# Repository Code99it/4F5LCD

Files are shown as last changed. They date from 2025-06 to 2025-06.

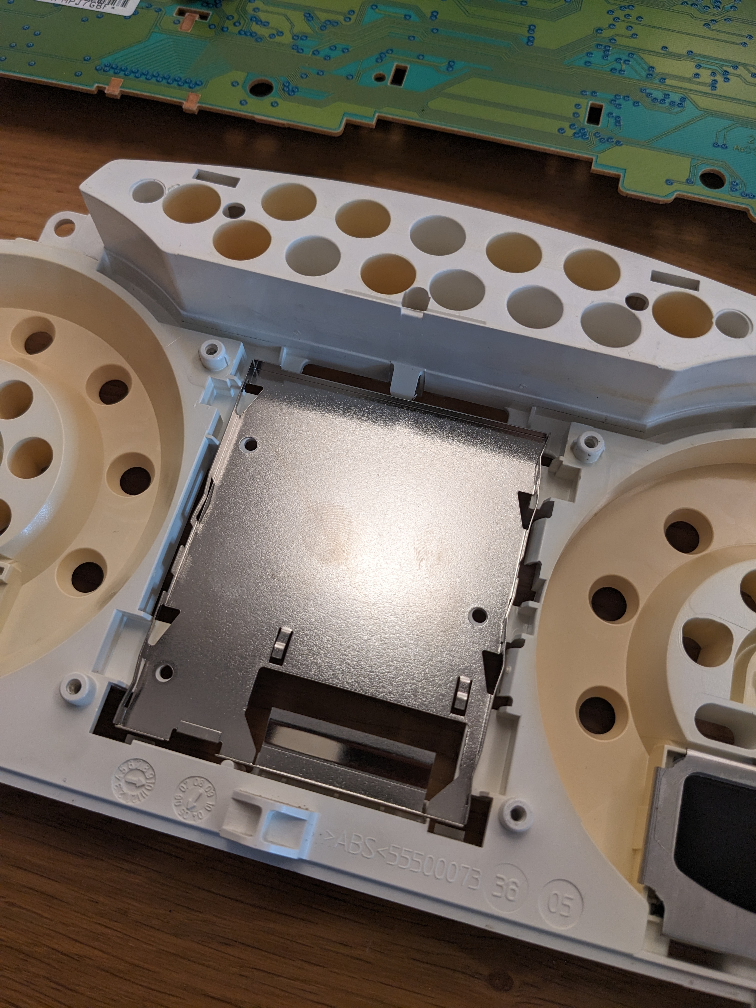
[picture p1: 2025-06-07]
Solution 2 - Disassembling the speedometer and fitting a 3.5 inch display/PXL_20250607_092634435.jpg

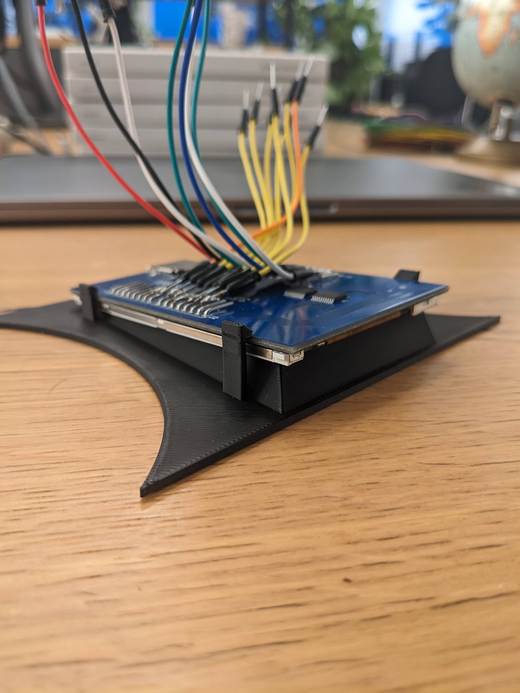
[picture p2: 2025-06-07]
Solution 1 - 3D printed mounting frame for the LCD/PXL_20250601_192043505.jpg

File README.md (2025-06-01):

# Installation und Nutzung  
# Installation and Usage  

**Dieses Projekt ersetzt bei Fahrzeugen der VAG-Gruppe mit Plattform 4F (C6) das kleine Display in der Mitte des Kombiinstruments durch eine spezielle Mikrocontroller-Lösung. Die Bedienung erfolgt über die linken Tasten am Lenkrad:**  
- Drehen am Rad wählt einen Listeneintrag.  
- Klicken auf das Drehrad aktiviert den gewählten Eintrag.  
- Die MODE-Taste am Lenkrad wechselt zwischen den Menüseiten.  
- Die Auf-Ab-Taste am Wischerhebel und die Bestätigungstaste auf der Hebel-Unterseite sind zunächst wirkungslos, die Funktion wird ggf. in späteren Projektversionen noch einmal aufgegriffen.

**This project replaces the small display in the center of the instrument cluster with a custom microcontroller solution for vehicles of the VAG group using platform 4F (C6). Operation is via the left steering wheel controls:**  
- Rotating the knob selects a list item.  
- Pressing the knob activates the selected item.  
- The MODE button on the steering wheel switches between menu pages.  
- The up/down button on the wiper stalk and the confirm button on the underside of the stalk are initially non-functional; this feature may be revisited in a future project version.

## Was dir dieses Projekt nützt  
## What This Project Does for You  

- Du erhältst schnellen, sicheren Zugriff auf fahrzeuginterne Statusdaten, um Temperatur-, Drehzahl- oder Komfortparameter zu überwachen.  
- You get fast, secure access to in-vehicle status data to monitor temperature, RPM, or comfort parameters.  

## 1. Systemzugriff einrichten  
## 1. Set Up System Access  

- Dieses System greift ausschließlich lesend auf die fahrzeuginternen Bussysteme (z. B. CAN-Bus) zu.  
- Es werden nur Statusinformationen wie Temperatur, Drehzahl oder Komfortdaten erfasst.  
- Kein Zugriff auf sicherheitskritische Systeme (Bremsen, Airbags, ESP, ABS, Antrieb).  
- Eine Beeinflussung, Veränderung oder Steuerung dieser Systeme ist weder vorgesehen noch implementiert.  

- No access to safety-critical systems (brakes, airbags, ESP, ABS, drivetrain).  
- Only status information such as temperature, RPM or comfort data is collected.  
- This system uses read-only access to the vehicle’s internal bus systems (e.g. CAN bus).  
- Any manipulation, alteration or control of these systems is neither intended nor implemented.  

## 2. Infotainment-Funktionen aktivieren  
## 2. Enable Infotainment Functions  

- Für Menüauswahl und Displayanzeige wird schreibender Zugriff auf nicht sicherheitsrelevante Steuergeräte verwendet.  
- Dieser Zugriff ist funktional begrenzt und beeinflusst weder Fahrverhalten noch Fahrsicherheit.  

- Write access to non-safety-critical control units is used for menu selection and display output.  
- This access is functionally limited and does not affect driving behavior or safety.  

## 3. CAN-Bus-Analyse durchführen  
## 3. Perform CAN-Bus Analysis  

- Sniffing im Rahmen des gesetzlich zulässigen Reverse Engineering (§ 69e UrhG) zur Interoperabilität.  
- Es wird keine Original-Software extrahiert, kopiert oder verändert – nur das Datenverhalten dokumentiert.  

- Sniffing under the legally permitted reverse engineering (§ 69e UrhG) for interoperability.  
- No original software is extracted, copied, or modified – only data behavior is documented.  

## 4. Nutzungshinweise  
## 4. Usage Notes  

- Du nutzt das System ausschließlich zu Test-, Entwicklungs- oder Forschungszwecken.  
- Dauerbetrieb im öffentlichen Straßenverkehr erfordert Einzelabnahme (§ 21 StVZO) bei TÜV/DEKRA etc.  

- Use exclusively for testing, development, or research purposes.  
- Permanent use on public roads requires single-vehicle approval (§ 21 StVZO) from TÜV/DEKRA, etc.  

## 5. Haftungsausschluss  
## 5. Disclaimer  

- Nicht autorisiert, geprüft oder freigegeben durch einen Fahrzeughersteller; keine offizielle Verbindung zu Herstellern der VAG-Gruppe.  
- Jegliche Nutzung erfolgt auf eigene Verantwortung.  

- Not authorized, tested, or approved by any vehicle manufacturer; no official affiliation with any brand of the VAG group.  
- Any use is at your own risk.

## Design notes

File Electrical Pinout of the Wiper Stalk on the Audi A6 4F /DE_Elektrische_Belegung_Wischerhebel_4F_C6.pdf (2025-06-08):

## Elektrische Belegung des Wischerhebels Audi A6 4F

Leitungen im Hebel: | Steckeranschluss:
rot | 1 | rot
gelb | 2 | gelb
grün | 3 | grün
4 | kein PIN
5 | nicht belegt
6 | nicht belegt

Widerstandsnetzwerk für die Tasten:

rot
grün

Widerstandsnetzwerk für den Drehgeber:

rot
gelb
Tastendruck | Leitungen | Widerstand
Reset | rot-grün | 330 Ohm
Up | rot-grün | 1,0 kOhm
Down | rot-grün | 2,5 kOhm
Stufe 1 (unten) | rot-gelb | 330 Ohm
Stufe 2 | rot-gelb | 1,0 kOhm
Stufe 3 | rot-gelb | 2,5 kOhm
Stufe 4 (oben) | rot-gelb | 8,7 kOhm

Spannungen am ADC-Eingang bei einem 3,3 kOhm Vorwiderstand/Spannungsteiler

Reset | rot-grün | 0,298 V
Up | rot-grün | 0,773 V
Down | rot-grün | 1,422 V
Stufe 1 (unten) | rot-gelb | 0,307 V
Stufe 2 | rot-gelb | 0,779 V
Stufe 3 | rot-gelb | 1,429 V
Stufe 4 (oben) | rot-gelb | 2,391 V

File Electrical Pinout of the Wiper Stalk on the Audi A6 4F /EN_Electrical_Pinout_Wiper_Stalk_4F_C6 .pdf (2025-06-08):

Electrical Pinout of the Wiper Stalk on the Audi A6 4F

Wires in Stalk: | Connector:
rot | 1 | red
gelb | 2 | yellow
grün | 3 | green
4 | no PIN
5 | nc
6 | nc

Resistor Network for the Buttons:
Red
Green

Resistor Network for the Rotary Switch: Red
Yellow

Button Presses & Measured Resistances:

Function | Wires | Resistance
Reset | Red-Green 330 Ohms
Up | Red-Green 1.0 kOhm
Down | Red-Green 2.5 kOhm
Step 1 (bottom) | Red-Yellow 330 Ohms
Step 2 Red-Yellow 1.0 kOhm
Step 3 Red-Yellow 2.5 kOhm
Step 4 (top) | Red-Yellow 8.7 kOhm

ADC Input Voltages with a 3.3 kΩ Series Resistor / Voltage Divider:

Function | Wires | Voltage (V)
Reset | Red-Green 0.298 V
Up | Red-Green 0.773 V
Down | Red-Green 1.422 V
Step 1 (bottom) | Red-Yellow 0.307 V
Step 2 Red-Yellow 0.779 V
Step 3 Red-Yellow 1.429 V
Step 4 (top) | Red-Yellow 2.391 V

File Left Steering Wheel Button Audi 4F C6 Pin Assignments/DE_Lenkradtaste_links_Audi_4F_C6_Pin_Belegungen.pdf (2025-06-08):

Lenkradtaste links

Audi 4F C6

Pin-Belegungen

Weißer 9-poliger Stecker direkt am Tastengehäuse

Ansicht von außen

Platine ist unten, Stecker ist rechts

1 | links | Inkrementalgeber A
2 | | ? evtl LED ?
3 | | Inkrementalgeber B
4 | | ? evtl LED ?
5 | | MODE-Taste
6 | | Inkrementalgeber COM
7 | | ? evtl LED ?
8 | | ? evtl LED ?
9 | rechts | Inkrementalgeber Taste

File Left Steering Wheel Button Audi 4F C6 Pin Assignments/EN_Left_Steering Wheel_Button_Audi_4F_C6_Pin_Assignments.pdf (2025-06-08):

Left Steering Wheel Button
Audi 4F C6
Pin Assignments

White 9-pin connector directly on the button housing Viewed from the outside
PCB is on the bottom, connector is on the right
Pin | Side | Function
1 | Left | Incremental Encoder A
2 | | ? Possibly LED ?
3 | | Incremental Encoder B
4 | | ? Possibly LED ?
5 | | MODE Button
6 | | Incremental Encoder COM
7 | | ? Possibly LED ?
8 | | ? Possibly LED ?
9 | Right | Incremental Encoder Button

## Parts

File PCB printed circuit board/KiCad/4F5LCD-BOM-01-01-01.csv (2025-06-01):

Reference | Qty | Value | DNP | Exclude from BOM | Exclude from Board | Footprint | Datasheet | Farnell
C101 | 1 | 10uF |  |  |  | Capacitor_SMD:CP_Elec_5x5.9 | ~ | 2346378
C102,C103 | 2 | 100n |  |  |  | Capacitor_SMD:C_1206_3216Metric_Pad1.33x1.80mm_HandSolder | ~ | 2495443
C104 | 1 | 1u |  |  |  | Capacitor_SMD:C_1206_3216Metric_Pad1.33x1.80mm_HandSolder | ~ | 2357339
C105 | 1 | 100nF |  |  |  |  | ~ | 2495443
C106 | 1 | 100nF |  |  |  | Capacitor_SMD:C_1206_3216Metric_Pad1.33x1.80mm_HandSolder | ~ | 2495443
C107,C108,C112,C113,C117,C118,C122,C123,C127,C128 | 10 | 18p |  |  |  | Capacitor_SMD:C_0603_1608Metric | ~ | 2905608
C109,C110,C114,C115,C119,C120,C124,C125,C129,C130 | 10 | 100n |  |  |  | Capacitor_SMD:C_1206_3216Metric | ~ | 2495443
D101 | 1 | MBRS340 |  |  |  | Diode_SMD:D_SMC | https://www.onsemi.com/download/data-sheet/pdf/mbrs340t3-d.pdf | 2824888
D102 | 1 | SMAJ33A |  |  |  | Diode_SMD:D_SMA | https://www.littelfuse.com/media?itemid=75e32973-b177-4ee3-a0ff-cedaf1abdb93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 | 4065376
F101 | 1 | 2A |  |  |  | Fuse:Fuse_Bourns_MF-SM_7.98x5.44mm | ~ | 3605928
J101 | 1 | Conn_01x10_Pin |  |  |  | 10153118-116KALF:AMPHENOL_10153118-116KALF | ~ | 3765468
J102 | 1 | Conn_02x16_Top_Bottom |  |  |  | Connector_IDC:IDC-Header_2x13-1MP_P2.54mm_Latch_Horizontal | ~ | 0000
J103 | 1 | 01x04 |  |  |  | Connector_Phoenix_MC:PhoenixContact_MC_1,5_2-G-3.81_1x02_P3.81mm_Horizontal | ~ | 3133790
J104 | 1 | 10159549-116KALF |  |  | Excluded from board |  |  | 3765470
J105,J106,J107,J108,J109,J110,J111,J112,J113,J114,J115,J116,J117,J118,J119,J120 | 16 | 10153126-4T2LF |  |  | Excluded from board |  | ~ | 3765472
J121 | 1 | 01x04 |  |  | Excluded from board | Connector_Phoenix_MC:PhoenixContact_MC_1,5_2-G-3.81_1x02_P3.81mm_Horizontal | ~ | 4244971
J122,J123,J124,J125 | 4 | Conn_01x01_Pin |  |  | Excluded from board |  | ~ | 1248246
L101 | 1 | 4.7uH |  |  |  | Inductor_SMD:L_Ferrocore_DLG-0403 | ~
NT102 | 1 | COM_GND |  | Excluded from BOM |  |  | ~
R101 | 1 | R |  |  |  |  | ~ | 1469856
U101 | 1 | TLS850C2TEV33 |  |  |  | Package_TO_SOT_SMD:TO-252-4 | https://fscdn.rohm.com/en/products/databook/datasheet/ic/power/linear_regulator/bdxxfc0wefj-e.pdf | 3680235
U102 | 1 | ESP32-S3-DEVKITC-1U-N8R2 |  |  |  | ESP32-S3-DEVKIT:XCVR_ESP32-S3-DEVKITC-1U-N8R2
U103,U105,U107,U109,U111 | 5 | MCP2515 |  |  |  | Package_SO:SOIC-18W_7.5x11.6mm_P1.27mm | http://ww1.microchip.com/downloads/en/DeviceDoc/21801e.pdf | 1292239
U104,U106,U108,U110,U112 | 5 | SN65HVD230 |  |  |  | Package_SO:SOIC-8_3.9x4.9mm_P1.27mm | http://www.ti.com/lit/ds/symlink/sn65hvd230.pdf | 3124671
Y101,Y102,Y103,Y104,Y105 | 5 | 16000000 |  |  |  | Crystal:Crystal_SMD_Abracon_ABM3-2Pin_5.0x3.2mm | ~ | 2832079

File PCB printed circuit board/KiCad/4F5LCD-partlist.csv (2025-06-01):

Id | Designator | Footprint | Quantity | Designation | Supplier and ref
1 | J103 | PhoenixContact_MC_1,5_2-G-3.81_1x02_P3.81mm_Horizontal | 1 | 02x02
2 | J102 | IDC-Header_2x13-1MP_P2.54mm_Latch_Horizontal | 1 | Conn_02x16_Top_Bottom
3 | J101 | AMPHENOL_10153118-116KALF | 1 | Conn_01x10_Pin
4 | U112,U104,U110,U108,U106 | SOIC-8_3.9x4.9mm_P1.27mm | 5 | SN65HVD230
5 | C130,C109,C121,C126,C115,C124,C114,C119,C111,C116,C129,C110,C125,C131,C120 | C_1206_3216Metric | 15 | 100n
6 | R106,R103,R104,R105,R102 | R_1206_3216Metric | 5 | 10k 1206
7 | C108,C128,C107,C117,C122,C112,C127,C123,C118,C113 | C_0603_1608Metric | 10 | 22p
8 | Y103,Y105,Y101,Y104,Y102 | Crystal_SMD_Abracon_ABM3-2Pin_5.0x3.2mm | 5 | 16000000
9 | U107,U109,U105,U111,U103 | SOIC-18W_7.5x11.6mm_P1.27mm | 5 | MCP2515-xSO
10 | C102,C103 | C_1206_3216Metric_Pad1.33x1.80mm_HandSolder | 2 | 100n
11 | U101 | TO-252-4 | 1 | TLS850C2TEV33
12 | U102 | XCVR_ESP32-S3-DEVKITC-1U-N8R2 | 1 | ESP32-S3-DEVKITC-1U-N8R2
13 | F101 | Fuse_Bourns_MF-SM_7.98x5.44mm | 1 | 2A
14 | D101 | D_SMC | 1 | MBRS340
15 | C104 | C_1206_3216Metric_Pad1.33x1.80mm_HandSolder | 1 | 1u
16 | C106 | C_1206_3216Metric_Pad1.33x1.80mm_HandSolder | 1 | 100nF
17 | C101 | CP_Elec_5x5.9 | 1 | 10uF
18 | L101 | L_Ferrocore_DLG-0403 | 1 | 4.7uH
19 | D102 | D_SMA | 1 | SMAJ33A

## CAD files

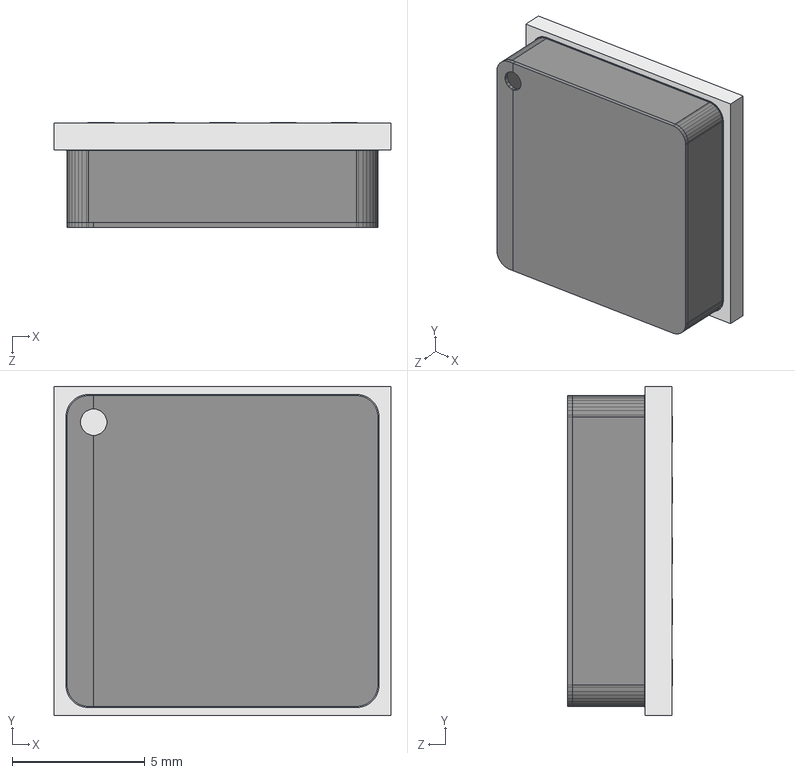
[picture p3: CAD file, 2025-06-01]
PCB printed circuit board/KiCad/TLS850C2TEV33/TLS850C2TEV33.step
12.7 x 12.4 x 3.97 mm

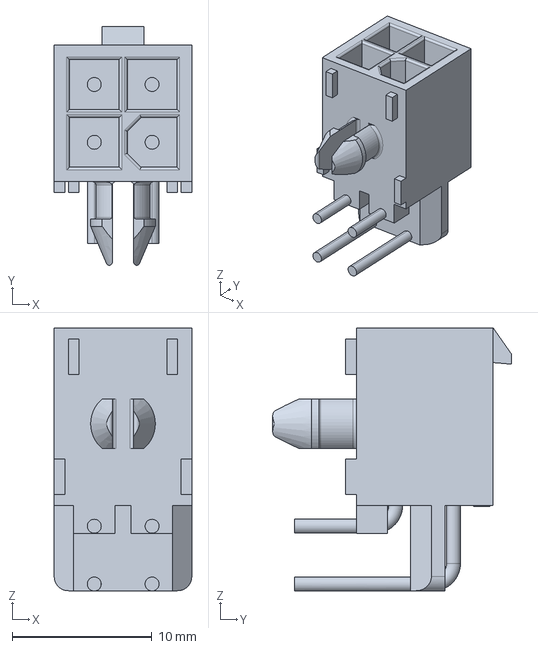
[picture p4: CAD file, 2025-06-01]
PCB printed circuit board/KiCad/ul_1-770968-0/c-1-770968-0-e-3d.stp
9.86 x 17.1 x 18.8 mm

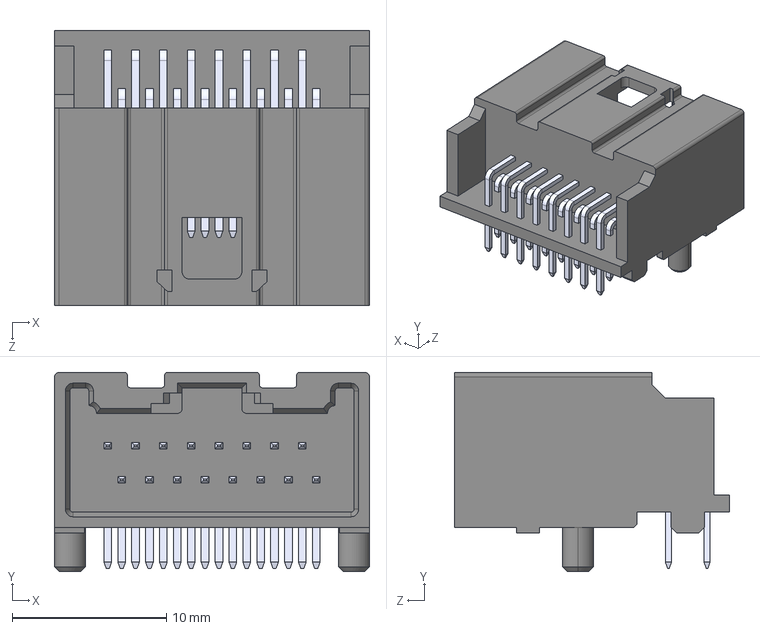
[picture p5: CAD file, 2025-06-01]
PCB printed circuit board/KiCad/CAN-Connector/10153118-116KALF/10153118-116KALF.step
20.4 x 12.9 x 17.8 mm
10153118-xxxKALF 2_16
pin^10153118-xxxKALF Ass 2 x 8

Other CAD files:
3D/Cover frame for LCD/4F5LCD-lcd-cover-frame.skp
3D/Housing for control unit/4F5LCD-housing-control-unit.skp

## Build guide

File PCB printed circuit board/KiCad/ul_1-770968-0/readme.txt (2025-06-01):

Notes:
 
1. All drill sizes are the maximum size provided by the manufacture (as required to calculate the minimum pad size).
2. All dimensions in building footprints are the maximum (including any tolerance) as defined by the manufacturer with the exception of row pitch (which is always nominal).  If only the normal sizing is provided we will input that dimension in mils, rounded to the nearest mil per our standards.
3. Slots are currently identified as entities describing the size of the slot (arcs, lines, etc.) on the board outline layer.  The extremities are identified with a via at each end.  These slots will either need to be:
	a. identified and dimensioned on your fabrication document
	b. or they will need to be converted to slots (assuming the targeted tool has a slot capability) using the process defined in your cad tool for identifying a padstack as a slot.  
		i. Typically this is only capable of a width and length of the slot and a size of the mill radius that creates the slot.  
		ii. Choosing to use the native tool slots will require removing entities on the board outline and the associated pads in the footprint.

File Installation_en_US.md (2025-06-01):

# Installation

Follow these steps for vehicles based on the 4F (C6) platform of the VAG group:

1. **Remove front trim**  
   Release the clips holding the instrument cluster’s front trim and carefully pull the trim away.

2. **Remove main screws**  
   Unscrew the four large metal screws around the instrument cluster.

3. **Remove instrument cluster**  
   Carefully pull the instrument cluster out of its housing and disassemble it as needed.

4. **Remove original display**  
   Gently lift the stock display out of its enclosure.

5. **Install new display**  
   Insert the replacement display module. Mount the associated microcontroller board in a suitable, insulated location.

6. **Reinstall front trim and main screws**  
   Slide the instrument cluster back into place, tighten all main screws, and snap the decorative trim back on.

7. **Attach Y-splitters to relevant control units**  
   - **Steering column electronics (e.g., J527):**  
     Located in the steering column behind the steering wheel. Remove the lower cover of the steering column and insert the Y-splitter between the original connector and the control unit.  
     
   - **Gateway control unit (e.g., J533 / diagnostic interface):**  
     Typically located on a support beam above the brake pedal behind the lower dashboard on the driver’s side. Remove the lower dashboard panel, locate the gateway connector, and insert the Y-splitter in line.

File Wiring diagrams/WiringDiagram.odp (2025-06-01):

## Project: 4F5LCD

4F5LCD is a custom display upgrade for the Audi A6 (C6, 4F series). It adds a secondary LCD screen without modifying or removing the original instrument cluster display. The new high-resolution display is mounted in a custom-designed bezel and positioned cleanly within the dashboard. It offers significantly improved visual quality and a wide range of configuration options compared to the factory display.

4F5LCD ist ein Display-Upgrade für den Audi A6 der Baureihe C6 (4F). Es ergänzt das originale Kombiinstrument um ein zusätzliches LCD-Display – ohne dieses zu verändern oder auszubauen. Das neue hochauflösende Display wird in einem eigens entwickelten Rahmen montiert und dezent im Innenraum integriert. Es bietet eine deutlich bessere Auflösung sowie wesentlich mehr Einstellmöglichkeiten als das originale Display.

## Wiring Diagram / Schaltplan

LCD

3.5”

320x480

OEM wiring harness

OEM 20-pin connector

8E0972420 female

originally connected

to the control unit

8E0972420 male

Y-splitter cable

8E0972420 male

26-pin flat cable

5x CAN-in

5x CAN-out

4F5LCD

CAN LCD Interface

J533

Gateway Control Module

OEM

12 V

GND

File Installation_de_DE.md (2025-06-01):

# Installation

Folge diesen Schritten für Fahrzeuge der Plattform 4F (C6) aus dem VAG-Konzern:

1. **Frontblende lösen**  
   Die Verriegelungen an der Frontblende des Kombiinstruments lösen und die Blende vorsichtig abziehen.

2. **Hauptschrauben entfernen**  
   Die vier großen Metallschrauben rund um das Kombiinstrument herausschrauben.

3. **Kombiinstrument ausbauen**  
   Das Kombiinstrument vorsichtig herausnehmen und in Einzelteile zerlegen.

4. **Original-Display ausbauen**  
   Das Displayelement behutsam aus dem Gehäuse entnehmen.

5. **Neues Display einsetzen**  
   Ersatzanzeige einsetzen. Die zugehörige Platine mit Mikrocontroller an geeigneter, isolierter Stelle unterbringen.

6. **Frontblende und Hauptschrauben montieren**  
   Kombiinstrument wieder einbauen, alle Schrauben sichern und die Dekor-Blende korrekt einrasten lassen.

7. **Y-Stecker an relevante Steuergeräte anschließen**  
   - **Steuergerät für Lenksäulenfunktionen (z. B. J527):**  
     Befindet sich in der Lenksäule hinter dem Lenkrad. Die Abdeckung unterhalb der Lenksäule entfernen und den Y-Stecker zwischen vorhandenen Stecker und das Steuergerät setzen.
     
   - **Gateway-Steuergerät (z. B. J533 / Diagnoseinterface):**  
     In der Regel auf einer Strebe oberhalb des Bremspedals im unteren Bereich des Armaturenbretts. Untere Verkleidung entfernen, Gateway-Stecker lokalisieren und Y-Adapter dazwischenstecken.

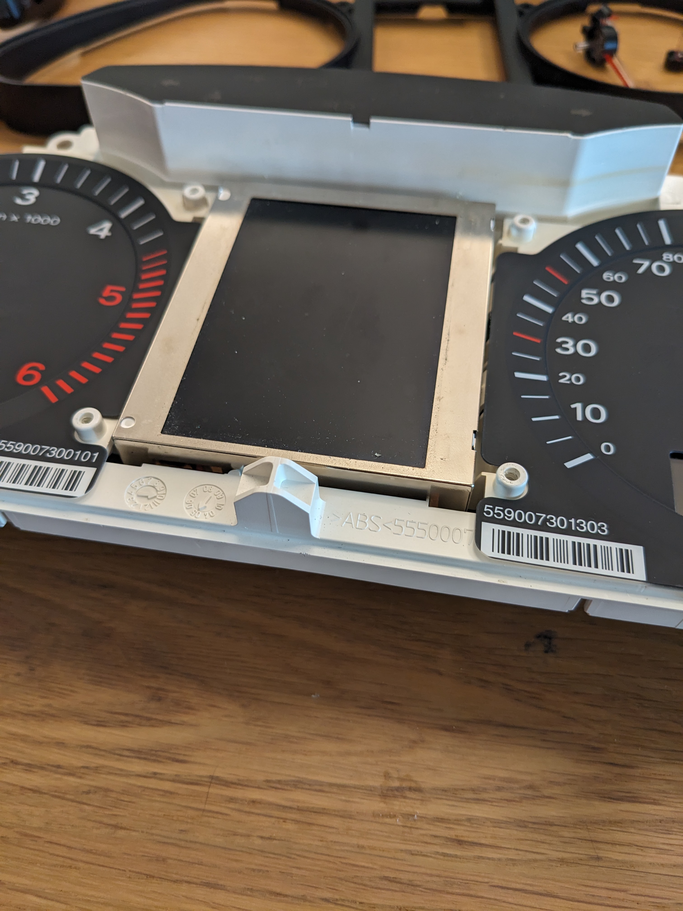
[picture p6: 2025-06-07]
Solution 2 - Disassembling the speedometer and fitting a 3.5 inch display/PXL_20250607_090449676.jpg

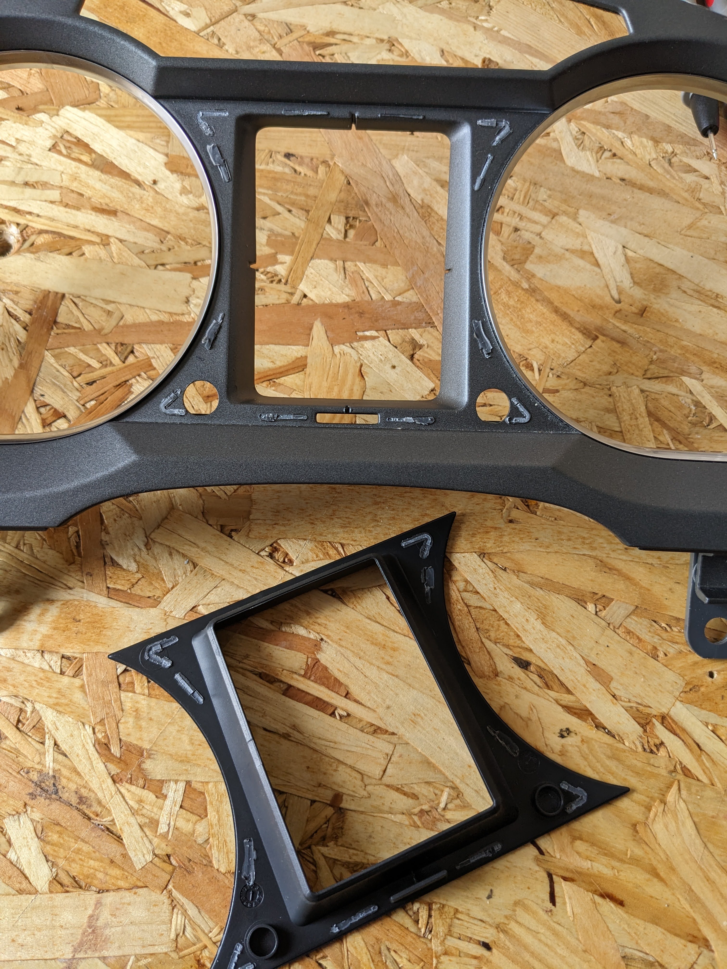
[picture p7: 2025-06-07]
Solution 1 - 3D printed mounting frame for the LCD/PXL_20250605_130331342.jpg

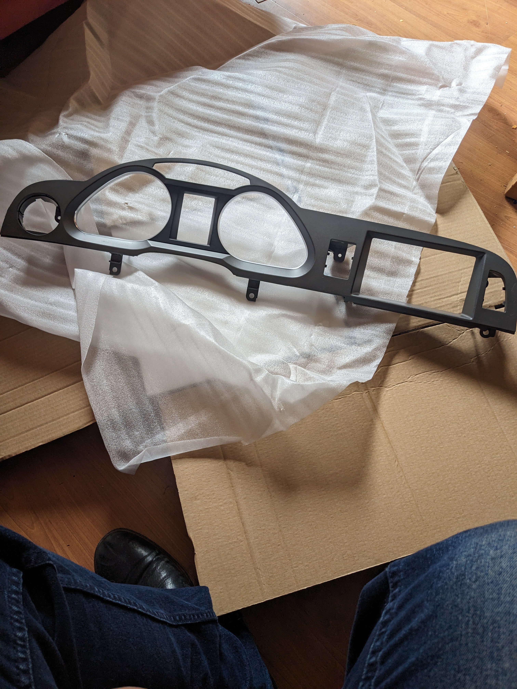
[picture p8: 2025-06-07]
Solution 1 - 3D printed mounting frame for the LCD/PXL_20250605_121213654.jpg

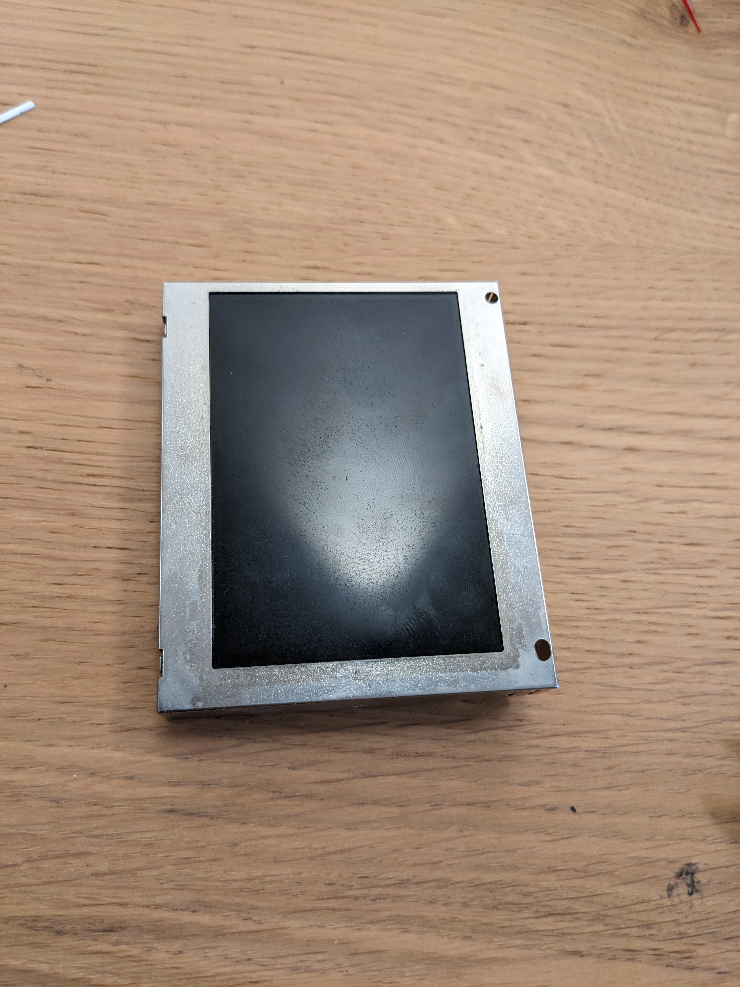
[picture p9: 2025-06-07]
Solution 2 - Disassembling the speedometer and fitting a 3.5 inch display/PXL_20250607_092157992.jpg

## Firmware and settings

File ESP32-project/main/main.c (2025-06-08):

#include <stdio.h>
#include <stdint.h>
#include <stdbool.h>
#include <string.h>

#include "freertos/FreeRTOS.h"
#include "freertos/task.h"
#include "esp_task_wdt.h"

#include "gpio.h"
#include "color.h"
#include "Code99-DRV-LCD-ILI9486-8-wire-parallel.h"
#include "Code99-API-LCD-ILI9486.h"

#include "driver/adc.h"
#include "esp_adc_cal.h"

#define DEFAULT_VREF    1100    // eFuse Vref (mV), kann angepasst werden
#define ADC_WIDTH       ADC_WIDTH_BIT_12
#define ADC_ATTEN       ADC_ATTEN_DB_11
#define ADC_RESOLUTION  4095.0
#define ADC_VREF        3.3     // interne Referenzspannung in Volt

// ADC-Kanäle (ADC1-GPIOs)
#define ADC_BUTTON_CHANNEL ADC1_CHANNEL_0  // GPIO36
#define ADC_DIAL_CHANNEL   ADC1_CHANNEL_7  // GPIO35

void app_main(void)
{
    // ADC1 initialisieren
    adc1_config_width(ADC_WIDTH);
    adc1_config_channel_atten(ADC_BUTTON_CHANNEL, ADC_ATTEN);
    adc1_config_channel_atten(ADC_DIAL_CHANNEL, ADC_ATTEN);

    float last_button_voltage = -1.0f;
    float last_dial_voltage = -1.0f;

    while (1) {
        int raw_button = adc1_get_raw(ADC_BUTTON_CHANNEL);
        int raw_dial   = adc1_get_raw(ADC_DIAL_CHANNEL);

        float voltage_button = (raw_button / ADC_RESOLUTION) * ADC_VREF;
        float voltage_dial   = (raw_dial   / ADC_RESOLUTION) * ADC_VREF;

        bool button_changed = (last_button_voltage < 0) ||
            (fabs(voltage_button - last_button_voltage) > 0.1f * last_button_voltage);

        bool dial_changed = (last_dial_voltage < 0) ||
            (fabs(voltage_dial - last_dial_voltage) > 0.1f * last_dial_voltage);

        if (button_changed || dial_changed) {
            printf("Button: %4d → %.3f V\tDial: %4d → %.3f V\n",
                   raw_button, voltage_button,
                   raw_dial, voltage_dial);

            last_button_voltage = voltage_button;
            last_dial_voltage   = voltage_dial;
        }

        vTaskDelay(pdMS_TO_TICKS(100));
    }

    /*

    printf("Initializing LCD driver (ILI9486)\n");
    lcd_driver_init();

    //printf("Initializing FPS test (Full screen)\n");
	//lcd_test_fill_fps();

    //printf("Initializing FPS test (Partial screen)\n");
    //lcd_test_fill_area_fps(0, 0, 320, 50, 50);

    printf("Filling screen: black\n");
    lcd_fill_color(hex_to_rgb565(0x000000));

    //printf("Filling screen: rainbow colors (10)\n");
	//lcd_fill_rainbow();
    
	uint16_t px_string_end;

	// lcd_draw_horizontal_line(uint16_t y, uint16_t width, uint16_t thickness, uint16_t color)
	printf("Drawing line below the header\n");
	lcd_draw_horizontal_line(61, 320, 3, hex_to_rgb565(0x990000));

	printf("Drawing line above the footer\n");
	lcd_draw_horizontal_line(414, 320, 3, hex_to_rgb565(0x990000));

	printf("Drawing gear\n");
	px_string_end = lcd_draw_colored_string("D", 145, 430, 29, 0xFFFFFF);
	lcd_draw_colored_string("4", px_string_end, 430, 29, 0X606060);

	printf("Drawing audio source\n");
	px_string_end = lcd_draw_colored_string("CD1", 11, 17, 24, 0xFF2E12);
	lcd_draw_colored_string("Thank You For The Music", px_string_end + 7, 17, 24, 0x505050);




	char *menu_items[] = {
		"BC1",
		"BC2",
		"BC3",
		"Suspension",
		"Automatic Transmission",
		"Contacts",
		"Radio",
		"Check",
		"Battery"
	};


	int framebuffer_width = LCD_PIXEL_WIDTH * 2;
	int framebuffer_height = 24;

	size_t framebuffer_size = framebuffer_width * framebuffer_height * sizeof(uint16_t);

	uint16_t *frmbuf_menubar = malloc(framebuffer_size);
	if (!frmbuf_menubar) {
	    printf("Fehler: Nicht genügend RAM für Framebuffer menubar\n");
	} else {
	    printf("Framebuffer für die gesamte Menübar, size=%d Bytes\n", (int)framebuffer_size);
	    printf("Framebuffer, width=%d Bytes\n", (int)framebuffer_width);
	    printf("Framebuffer, height=%d Bytes\n", (int)framebuffer_height);
	}

	// Framebuffer komplett mit Farbe auffüllen
	for (int i = 0; i < framebuffer_width * framebuffer_height; i++) {
		frmbuf_menubar[i] = hex_to_rgb565(0x000000); // Schwarz
	}



	// Menüpunkt 0 zentriert anzeigen
	uint16_t centered_menu_item_end_x = lcd_draw_colored_string_centered_at_x_to_frmbuf(
	    frmbuf_menubar,
	    framebuffer_width,
	    menu_items[3],  
	    LCD_PIXEL_WIDTH / 2,       
	    0,
	    13,
	    0x3232FF   
	);
    printf("Endpunkt des Mittigen Strings = %d px\n", (int)centered_menu_item_end_x);

	// Menüpunkt 1 direkt rechts daneben (nicht zentriert!)
	uint16_t second_menu_item_end_x = lcd_draw_colored_string_to_frmbuf(
	    frmbuf_menubar,
	    framebuffer_width,
	    menu_items[4],    
	    centered_menu_item_end_x + MENU_ITEM_SPACING_PX,  // Mit kleinem Abstand anschließen
	    0,
	    13,
	    0x404040
	);	

	uint16_t third_menu_item_end_x = lcd_draw_colored_string_to_frmbuf(
	    frmbuf_menubar,
	    framebuffer_width,
	    menu_items[5],    
	    second_menu_item_end_x + MENU_ITEM_SPACING_PX,  // Mit kleinem Abstand anschließen
	    0,
	    13,
	    0x404040
	);
	
	lcd_draw_colored_string_to_frmbuf(
	    frmbuf_menubar,
	    framebuffer_width,
	    menu_items[6],    
	    third_menu_item_end_x + MENU_ITEM_SPACING_PX,  // Mit kleinem Abstand anschließen
	    0,
	    13,
	    0x404040
	);



	lcd_draw_framebuffer_region(   
	    frmbuf_menubar,        // Zeiger auf den vollständigen Framebuffer (doppelte LCD-Breite)  
	    framebuffer_width,     // Tatsächliche Breite des Framebuffers in Pixeln (z. B. LCD_PIXEL_WIDTH * 2)  
	    0,                     // X-Versatz im Framebuffer: beginnt bei 0, also linke Seite anzeigen  
	    0,                     // Y-Versatz im Framebuffer: beginnt bei oberster Zeile  
	    LCD_PIXEL_WIDTH,       // Breite des anzuzeigenden Ausschnitts (exakt LCD-Breite)  
	    framebuffer_height,    // Höhe des Ausschnitts in Pixeln (z. B. 24px für Menübar)  
	    0,                     // X-Position auf dem LCD, an der der Ausschnitt dargestellt wird  
	    96                     // Y-Position auf dem LCD (z. B. vertikal unterhalb eines Headers)  
	);




	lcd_draw_centered_rounded_frame(
	    menu_items[3],      // Textstring (z. B. "BC1"), um den der Rahmen gezeichnet wird
	    160,                // Mittelpunkt auf dem LCD in X-Richtung (horizontal zentriert)
	    95,                  // Y-Position des oberen Rahmens (Startpunkt vertikal)
	    13,                 // Schriftgröße in Pixelhöhe (z. B. 13px)
	    5,                  // Innenabstand (Padding) zwischen Text und Rahmen in Pixeln
	    2,                  // Rahmenbreite (Thickness) in Pixeln
	    5,                  // Radius der gerundeten Ecken in Pixeln
	    0x2424FF            // Rahmenfarbe in Hex 
	);


	vTaskDelay(pdMS_TO_TICKS(3000));

	// Rahmen entfernen
	lcd_delete_centered_rounded_frame(
	    menu_items[3],      // Textinhalt
	    160,                // Zentrierung X
	    95,                 // Position Y
	    13,                 // Schriftgröße
	    5,                  // Padding
	    2,                  // Rahmenbreite
	    5,                  // Eckenradius
	    0x000000            // Hintergrundfarbe
	);

	// Entfärbten aktuellen Menüpunkt zeigen
	// Menüpunkt 0 zentriert anzeigen
	lcd_draw_colored_string_centered_at_x_to_frmbuf(
	    frmbuf_menubar,
	    framebuffer_width,
	    menu_items[3],  
	    LCD_PIXEL_WIDTH / 2,       
	    0,
	    13,
	    0x404040   
	);

	// in einer schleife zum nächsten menüpunkt gehen
	// framebuffer immer wieder neu zeichnen
	for (uint8_t left_cut=0; left_cut<189; left_cut++) {
		lcd_draw_framebuffer_region(   
		    frmbuf_menubar,        // Zeiger auf den vollständigen Framebuffer (doppelte LCD-Breite)  
		    framebuffer_width,     // Tatsächliche Breite des Framebuffers in Pixeln (z. B. LCD_PIXEL_WIDTH * 2)  
		    left_cut,              // X-Versatz im Framebuffer: beginnt bei 0, also linke Seite anzeigen  
		    0,                     // Y-Versatz im Framebuffer: beginnt bei oberster Zeile  
		    LCD_PIXEL_WIDTH,       // Breite des anzuzeigenden Ausschnitts (exakt LCD-Breite)  
		    framebuffer_height,    // Höhe des Ausschnitts in Pixeln (z. B. 24px für Menübar)  
		    0,                     // X-Position auf dem LCD, an der der Ausschnitt dargestellt wird  
		    96                     // Y-Position auf dem LCD (z. B. vertikal unterhalb eines Headers)  
		);
		//vTaskDelay(pdMS_TO_TICKS(2));
	}

	lcd_draw_centered_rounded_frame(
	    menu_items[4],      // Textstring (z.B. "BC1"), um den der Rahmen gezeichnet wird
	    160,                // Mittelpunkt auf dem LCD in X-Richtung (horizontal zentriert)
	    95,                  // Y-Position des oberen Rahmens (Startpunkt vertikal)
	    13,                 // Schriftgröße in Pixelhöhe (z. B. 13px)
	    5,                  // Innenabstand (Padding) zwischen Text und Rahmen in Pixeln
	    2,                  // Rahmenbreite (Thickness) in Pixeln
	    5,                  // Radius der gerundeten Ecken in Pixeln
	    0x2424FF            // Rahmenfarbe in Hex 
	);


	printf("Drawing some keys and values\n");
	lcd_draw_colored_string("D: shift up +", 51, 150, 24, 0xa8a8a8);
	lcd_draw_colored_string("D: shift dn -", 51, 190, 24, 0xa8a8a8);
	lcd_draw_colored_string("S: shift up +", 51, 230, 24, 0xa8a8a8);
	lcd_draw_colored_string("S: shift dn -", 51, 270, 24, 0xa8a8a8);
	lcd_draw_colored_string("M: shift up +", 51, 310, 24, 0xa8a8a8);
	lcd_draw_colored_string("M: shift dn -", 51, 350, 24, 0xa8a8a8);

	lcd_draw_colored_string("3100", 248, 150, 24, 0xFFFFFF);
	lcd_draw_colored_string("1400", 248, 190, 24, 0xFFFFFF);
	lcd_draw_colored_string("4000", 248, 230, 24, 0xFFFFFF);
	lcd_draw_colored_string("1900", 248, 270, 24, 0xFFFFFF);
	lcd_draw_colored_string("4500", 248, 310, 24, 0xFFFFFF);
	lcd_draw_colored_string("1600", 248, 350, 24, 0xFFFFFF);








	// Alle Parameter definieren
	uint16_t ring_diameter = 24;
	uint16_t ring_thickness = 3;
	uint16_t center_diameter = 14;
	uint16_t line_length = 16;
	uint16_t line_thickness = 2;
	uint16_t padding = 0;

	// Berechnung der Framebuffergröße
	uint16_t fb_width = ring_diameter + line_length + 2 + padding * 2;
	uint16_t fb_height = ring_diameter + padding * 2;

	// Dynamischen Speicher allokieren
	uint16_t *select_fb = malloc(fb_width * fb_height * sizeof(uint16_t));
	if (!select_fb) {
	    printf("Fehler: Nicht genügend RAM für Framebuffer\n");
	    return;
	}

	// Framebuffer löschen
	memset(select_fb, 0, fb_width * fb_height * sizeof(uint16_t));

    printf("Starting main loop\n");
    printf("Quit monitor: Control+] (Control+Option+6)\n");

    while (true)
    {

		for (uint16_t pointerpos=152; pointerpos <=352; pointerpos+=40) {

			// Draw Line Selector into frame buffer
			lcd_draw_menu_select_point(
			    select_fb,
			    fb_width,
			    fb_height,
			    padding,       // x_offset
			    padding,       // y_offset
			    ring_diameter,
			    ring_thickness,
			    center_diameter,
			    0xFF0000,      // ring_color
			    0xA0A0A0,      // center_color
			    0xFF0000,      // line_color
			    line_length,
			    line_thickness,
			    0x000000       // background (schwarz)
			);

			// Transmit Frame Buffer to LCD
			lcd_blit_framebuffer(select_fb, fb_width, fb_height, 7, pointerpos);

			// Wait...
			vTaskDelay(pdMS_TO_TICKS(1000));

			// Fill Framebuffer black
			lcd_fill_framebuffer(select_fb, fb_width, fb_height, 0x000000);  

			// Transmit Frame Buffer to LCD
			lcd_blit_framebuffer(select_fb, fb_width, fb_height, 7, pointerpos);
		}

    }

    // Speicher freigeben
	free(select_fb);
	*/
}

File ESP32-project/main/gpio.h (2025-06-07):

/**
 * @file gpio.h
 * 
 * @brief GPIO pin definitions for 8-bit parallel LCD interface (ESP32-S3)
 * 
 * @author Christian Wilhelm (cw1@code99.it)
 * @version 1.0.1
 * @date 2025-06-02
 *
 * This file defines the GPIO mappings for data and control signals
 * used to connect an 8-bit parallel LCD to the ESP32-S3. All selected
 * pins are safe to use — they are not reserved for flash, USB, or
 * bootstrapping, and are fully output-capable.
 * 
 */

#ifndef GPIO_H
#define GPIO_H

#include <stdint.h>
#include "driver/gpio.h"

// LCD Data wires (should be in a continous row)
#define LCD_DATA_0 GPIO_NUM_35
#define LCD_DATA_1 GPIO_NUM_36
#define LCD_DATA_2 GPIO_NUM_37
#define LCD_DATA_3 GPIO_NUM_38
#define LCD_DATA_4 GPIO_NUM_39
#define LCD_DATA_5 GPIO_NUM_40
#define LCD_DATA_6 GPIO_NUM_41
#define LCD_DATA_7 GPIO_NUM_42

// LCD Command wires
#define LCD_RD   GPIO_NUM_14   
#define LCD_WR   GPIO_NUM_15
#define LCD_RS   GPIO_NUM_16   
#define LCD_CS   GPIO_NUM_17  
#define LCD_RST  GPIO_NUM_18

#define HIGH true
#define LOW false

#endif

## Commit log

2025-06-01 Refactored project structure, added missing files, and created required folders.
    [100powersupply.kicad_sch, 10153118-116KALF.step, 200mcuesp32.kicad_sch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]
2025-06-02 wrote entire esp32 project new, created new c and h files, improved LCD FPS from 1 to 6.8
2025-06-07 Photos: Solution with a 3D-printed mounting frame for the LCD
2025-06-07 changed and added display drivers
2025-06-08 added electrical pinout for wiper stalk
    [4F5LCDBOM.csv, Hardware list.ods]
2025-06-08 added wiring diagram for left steering wheel buttons
